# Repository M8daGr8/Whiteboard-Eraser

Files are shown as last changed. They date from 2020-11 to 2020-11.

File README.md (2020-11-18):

# Whiteboard Eraser
Joystick controlled whiteboard eraser.

## Joystick
### PCB
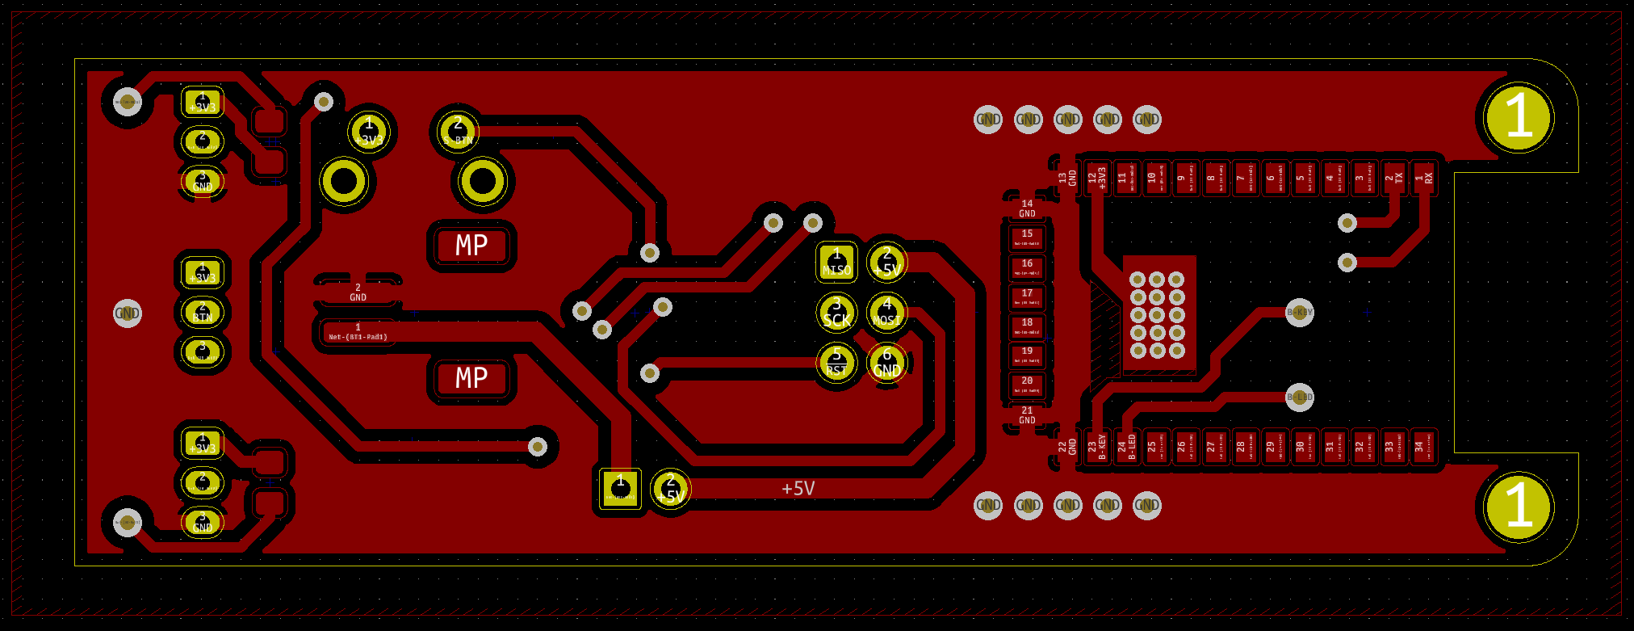
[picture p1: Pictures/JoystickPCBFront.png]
Joy-PCB-Front Joystick PCB Front

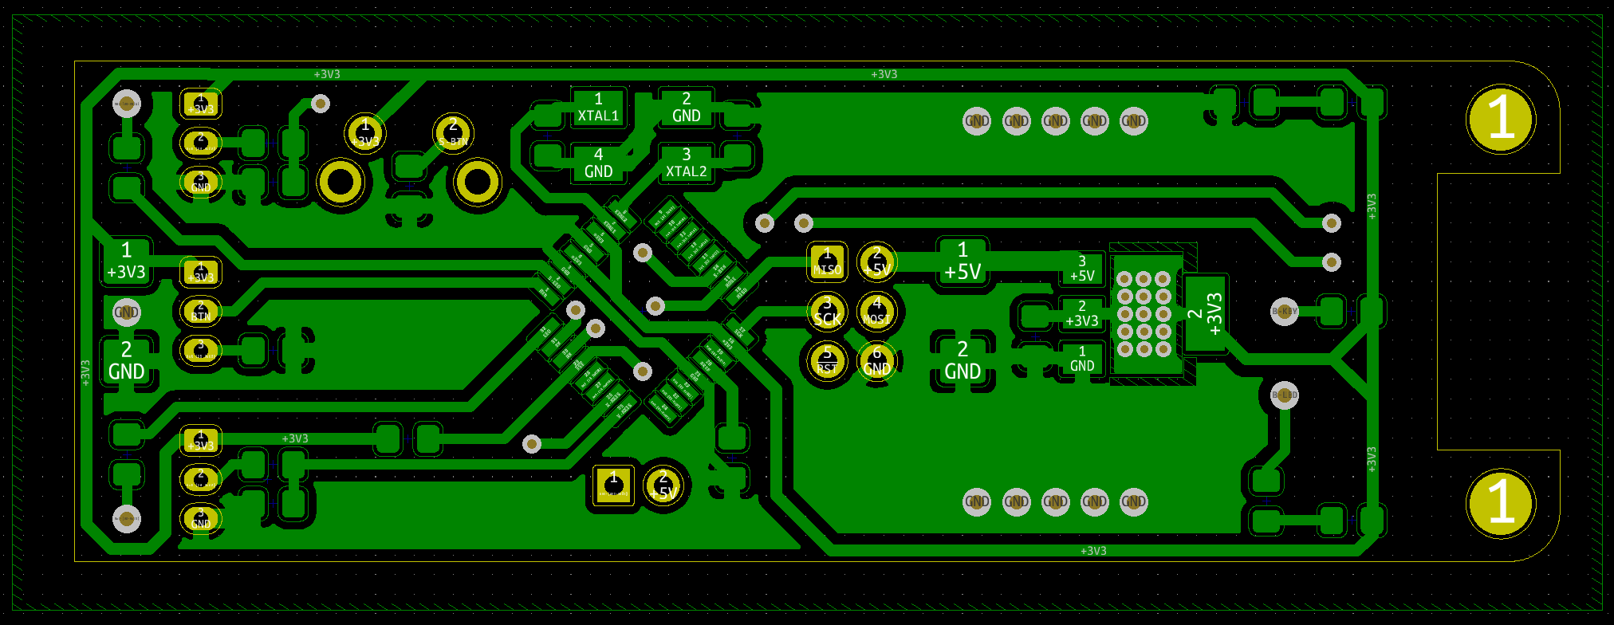
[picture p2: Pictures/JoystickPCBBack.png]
Joy-PCB-Back Joystick PCB Back

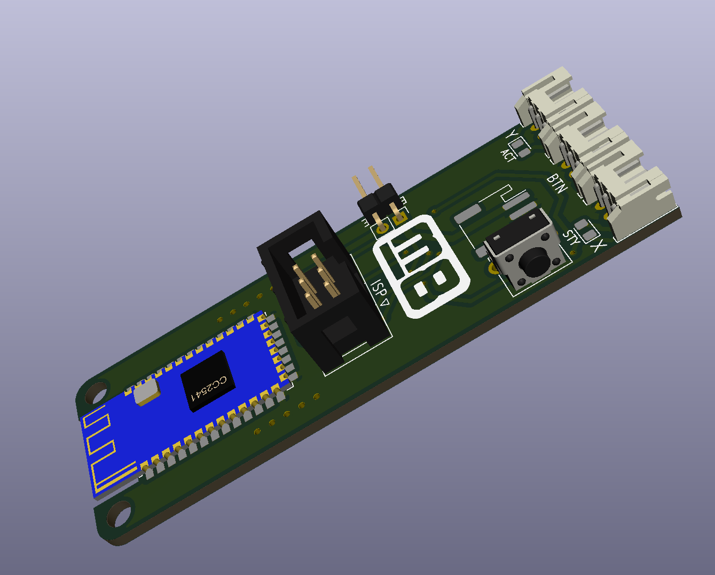
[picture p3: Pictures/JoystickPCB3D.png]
Joy-PCB-3D Joystick PCB 3D


### CAD
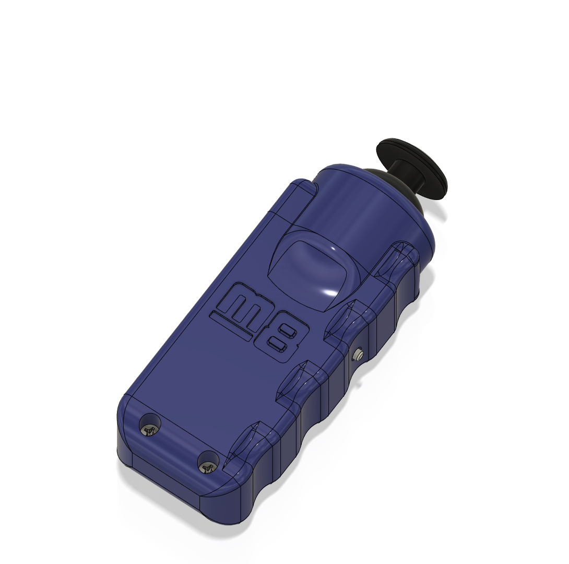
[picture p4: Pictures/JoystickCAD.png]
Joy-CAD Joystick CAD


## Eraser
### PCB
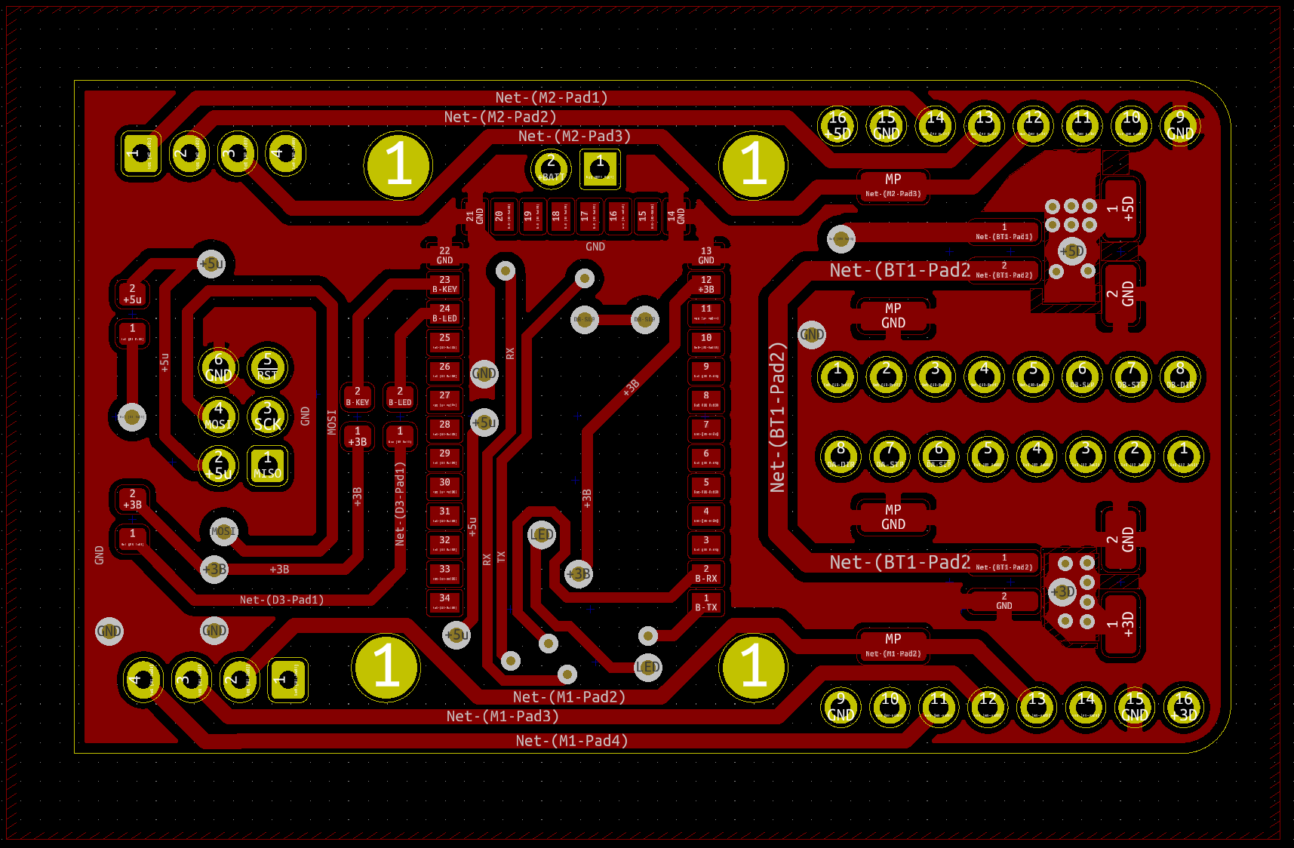
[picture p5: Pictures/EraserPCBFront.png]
Era-PCB-Front Eraser PCB Front

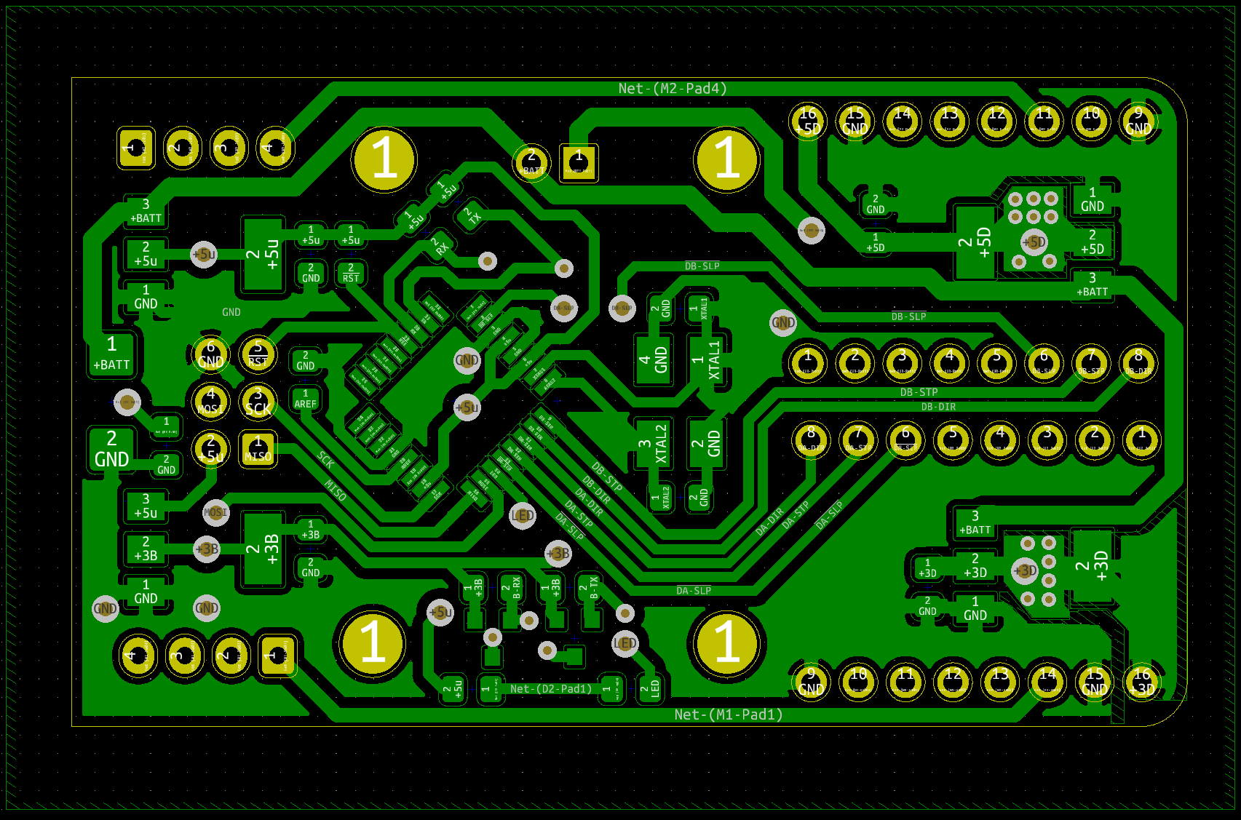
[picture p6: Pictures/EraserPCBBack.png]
Era-PCB-Back Eraser PCB Back

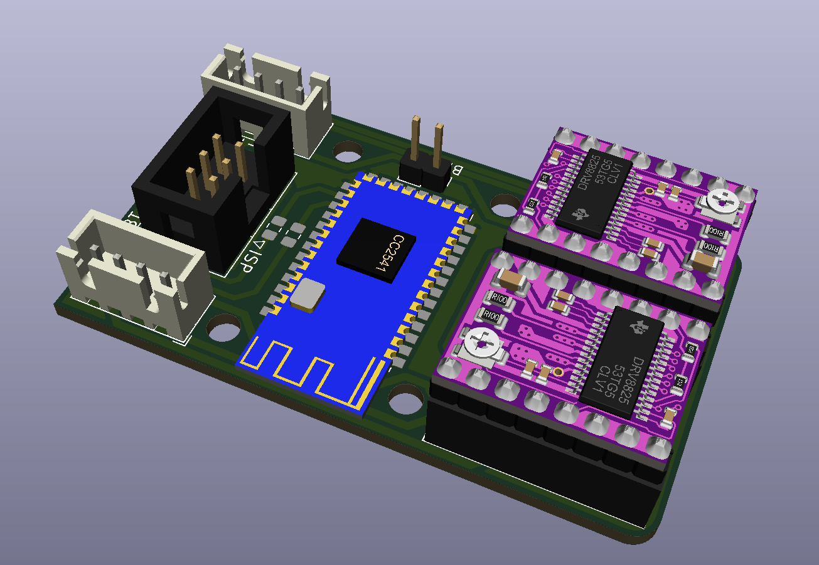
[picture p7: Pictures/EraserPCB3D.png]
Era-PCB-3D Eraser PCB 3D


### CAD
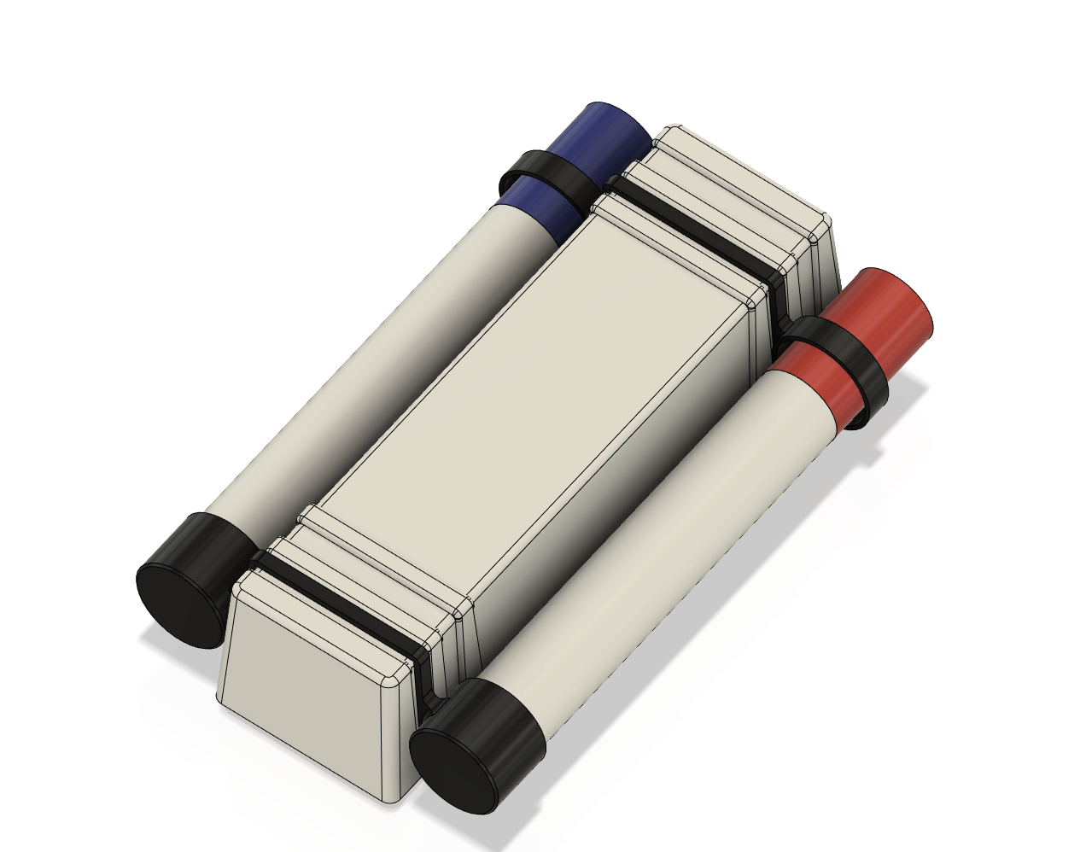
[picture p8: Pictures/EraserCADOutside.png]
Era-CAD-Outside Eraser CAD Outside

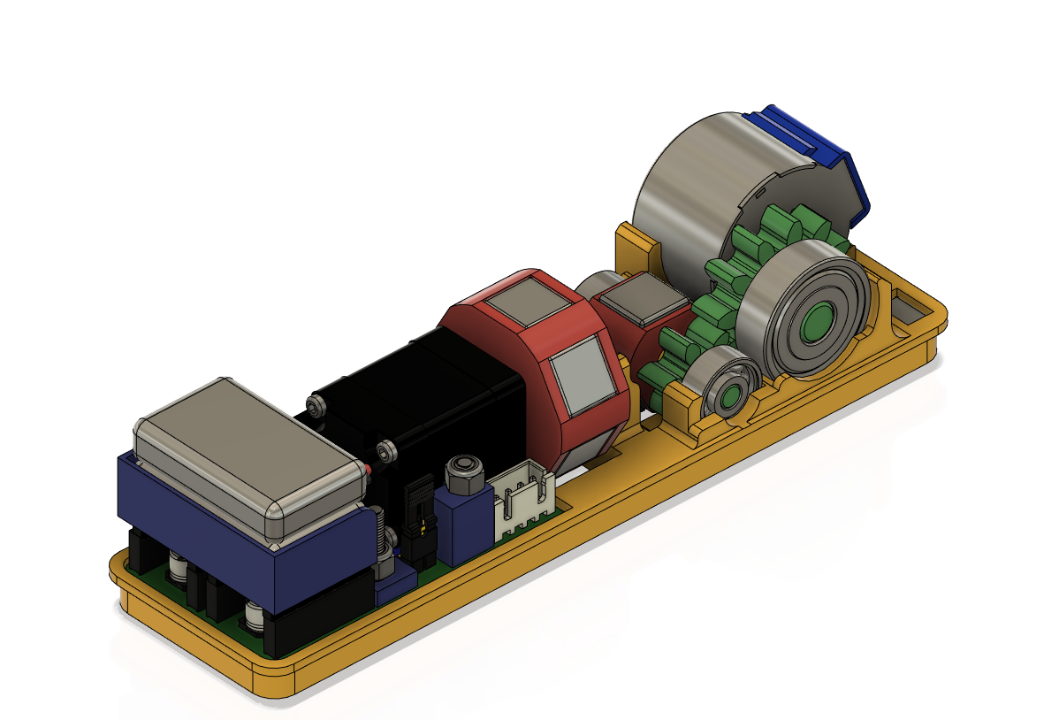
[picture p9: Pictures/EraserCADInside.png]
Era-CAD-Inside Eraser CAD Inside

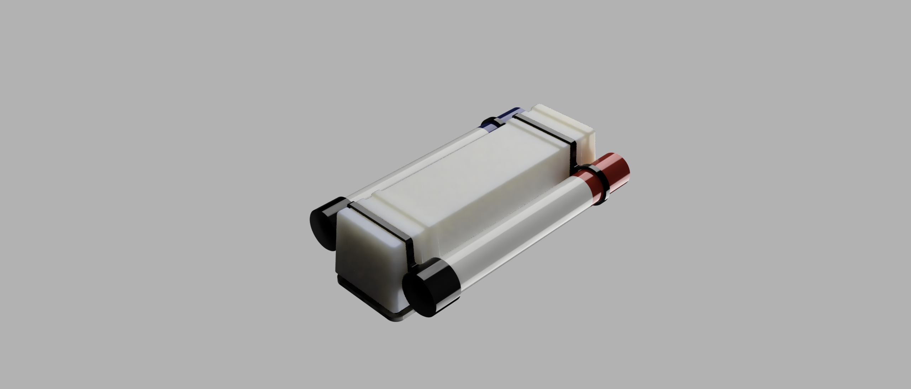
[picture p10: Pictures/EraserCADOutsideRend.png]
Era-CAD-Outside-Rend Eraser CAD Outside Rendered

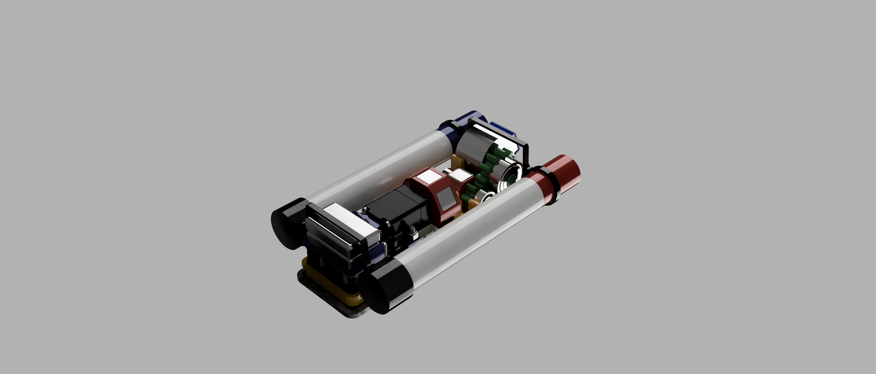
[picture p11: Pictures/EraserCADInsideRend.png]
Era-CAD-Inside-Rend Eraser CAD Inside Rendered


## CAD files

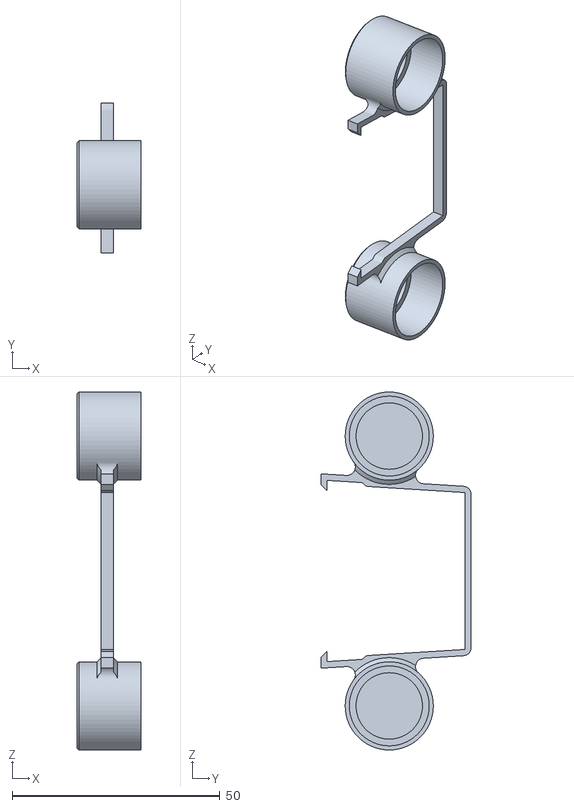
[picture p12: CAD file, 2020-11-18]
Eraser/STL/PenHolderBottom.stl
15.5 x 36.2 x 86.2

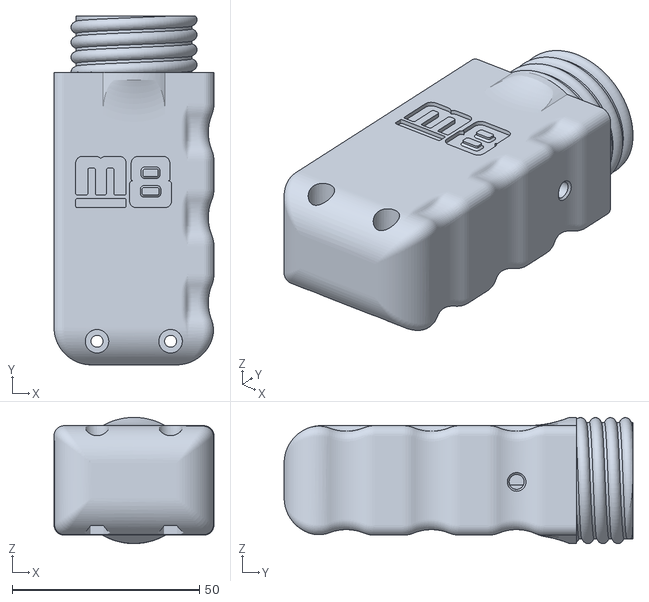
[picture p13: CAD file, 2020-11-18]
Joystick/STL/Handle.stl
42.8 x 93.2 x 33.7

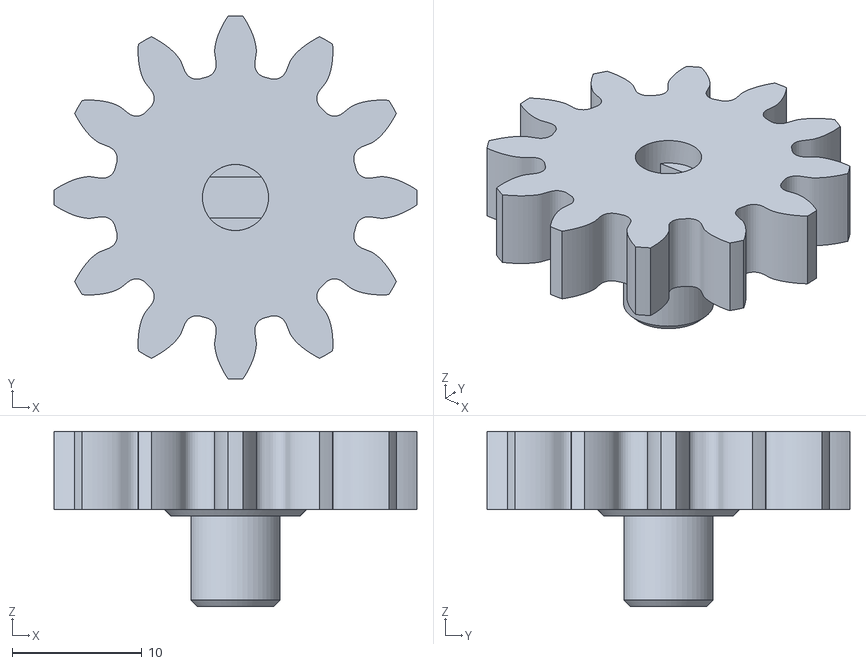
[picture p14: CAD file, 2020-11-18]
Eraser/STL/Y-Axis_Gear(12).stl
28.0 x 28.0 x 13.5

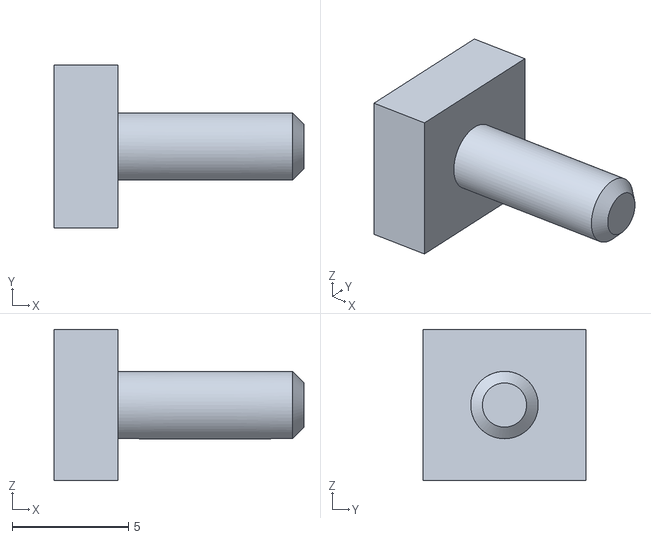
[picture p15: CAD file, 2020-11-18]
Joystick/STL/Button.stl
10.7 x 7.00 x 6.50

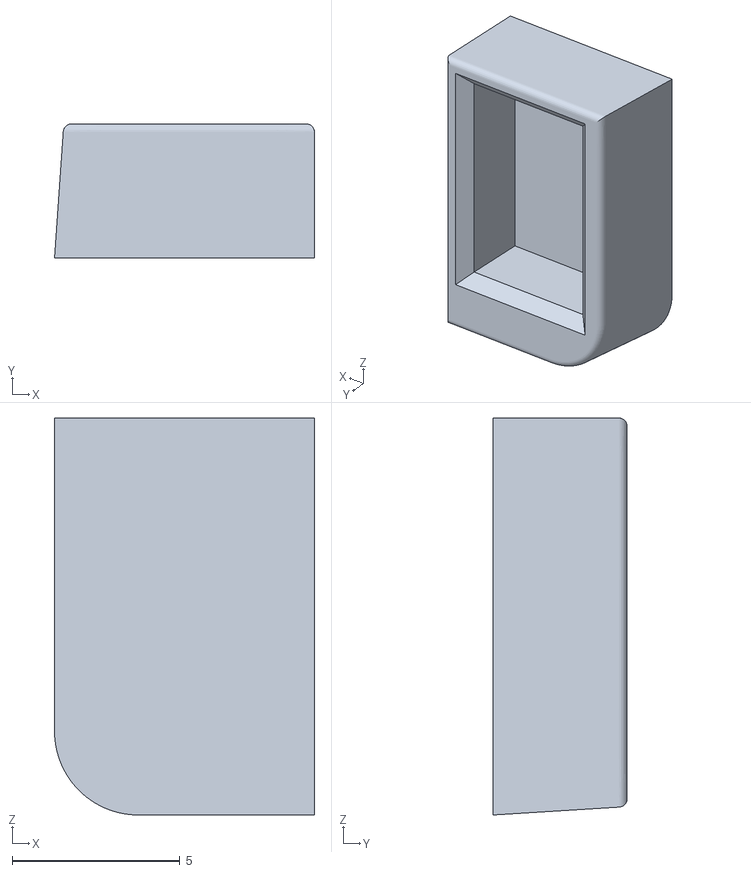
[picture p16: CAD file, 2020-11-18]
Eraser/STL/CoverMagnet.stl
7.74 x 4.00 x 11.8

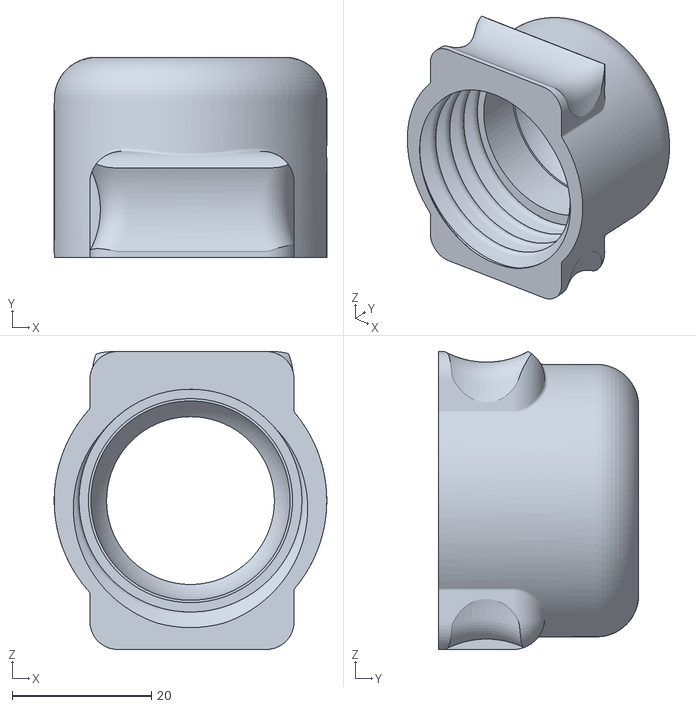
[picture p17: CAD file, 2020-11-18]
Joystick/STL/JoystickCover.stl
39.1 x 28.8 x 42.8

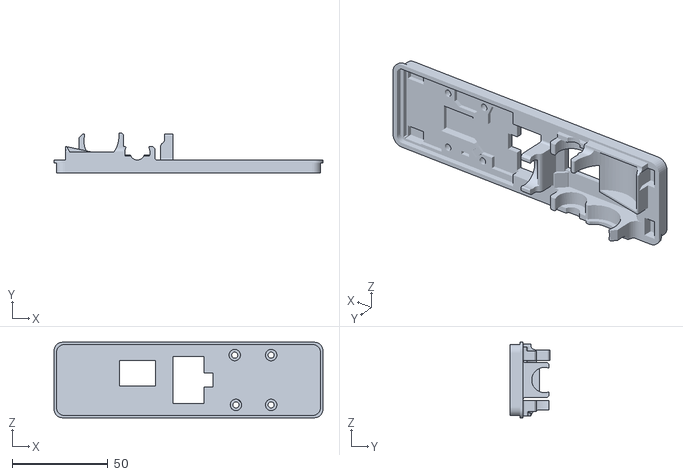
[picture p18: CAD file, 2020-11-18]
Eraser/STL/PCB Base.stl
140.7 x 20.8 x 39.5

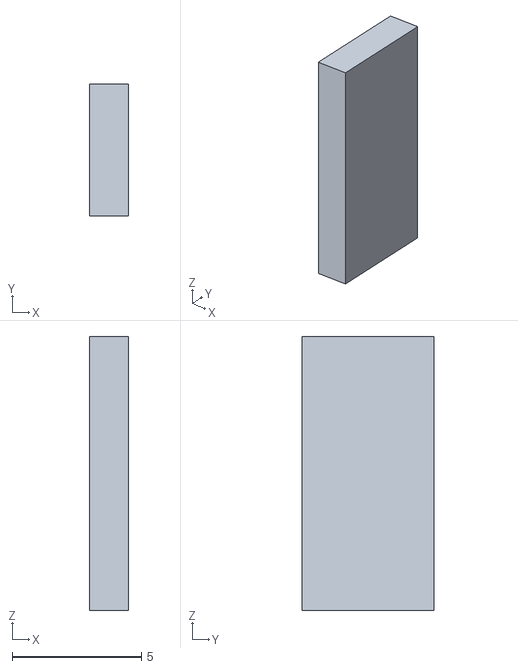
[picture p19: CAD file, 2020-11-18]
Joystick/STL/MagnetCover.stl
1.50 x 5.10 x 10.6

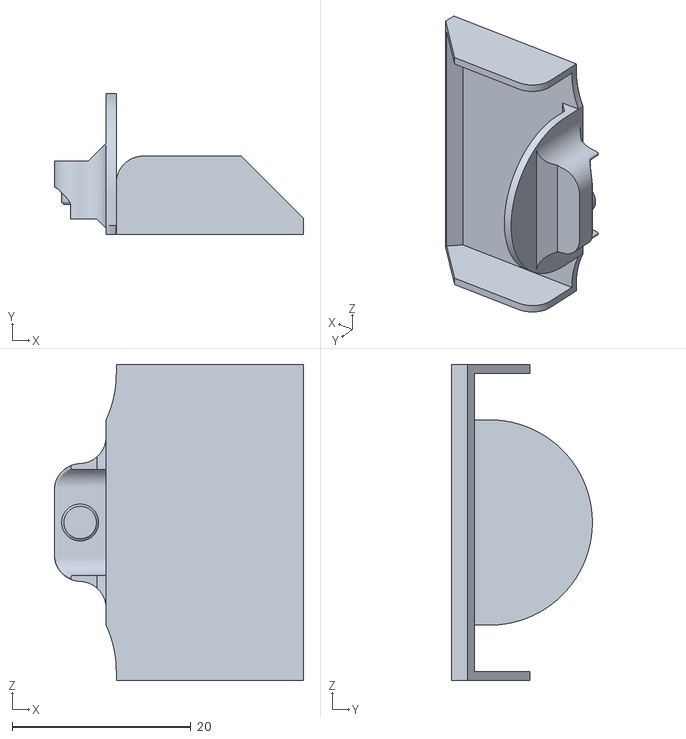
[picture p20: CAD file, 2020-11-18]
Eraser/STL/BatteryHolder.stl
27.9 x 15.8 x 35.4

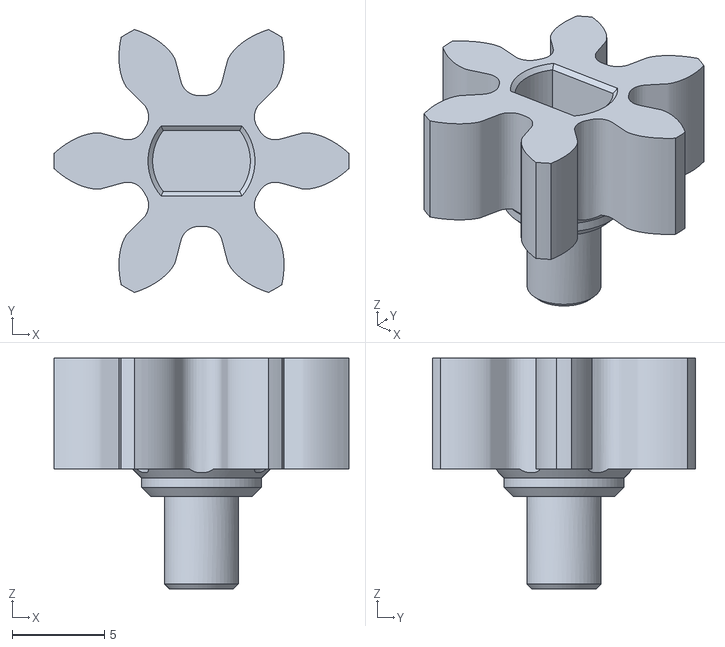
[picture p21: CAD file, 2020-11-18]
Eraser/STL/Y-Axis_Gear(6).stl
16.0 x 14.3 x 12.5

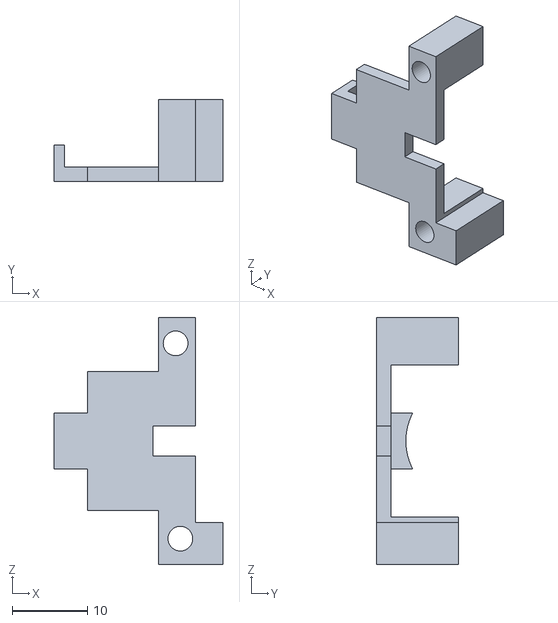
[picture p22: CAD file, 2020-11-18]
Eraser/STL/StepperHolderFront.stl
22.5 x 10.9 x 32.9

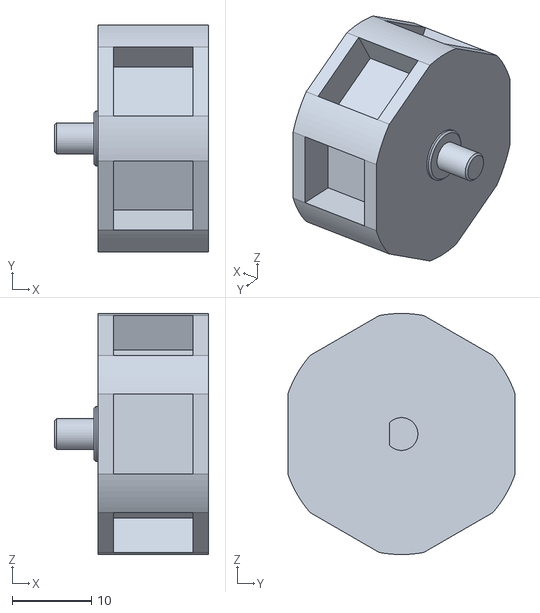
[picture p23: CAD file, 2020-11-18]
Eraser/STL/X-Axis_Wheel(10x10x5mm).stl
19.5 x 28.8 x 30.5

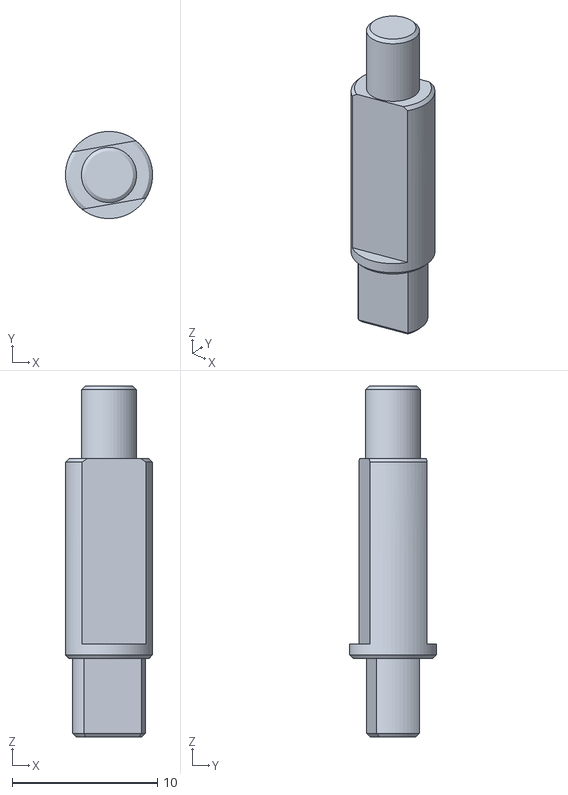
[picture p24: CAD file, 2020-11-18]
Eraser/STL/Y-Axis_Shaft.stl
6.00 x 6.00 x 24.2

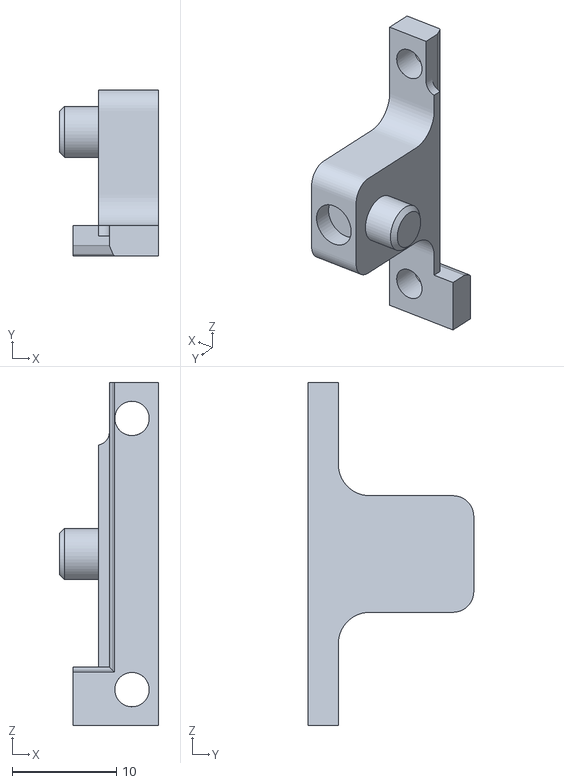
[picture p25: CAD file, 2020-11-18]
Eraser/STL/StepperHolderBack.stl
9.55 x 15.9 x 32.9

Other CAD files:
Eraser/STL/PenHolderTop.stl
Eraser/STL/Y-Axis_Wheel(8x4mm).stl
Eraser/STL/Y-Axis_Wheel(10x10x5mm).stl

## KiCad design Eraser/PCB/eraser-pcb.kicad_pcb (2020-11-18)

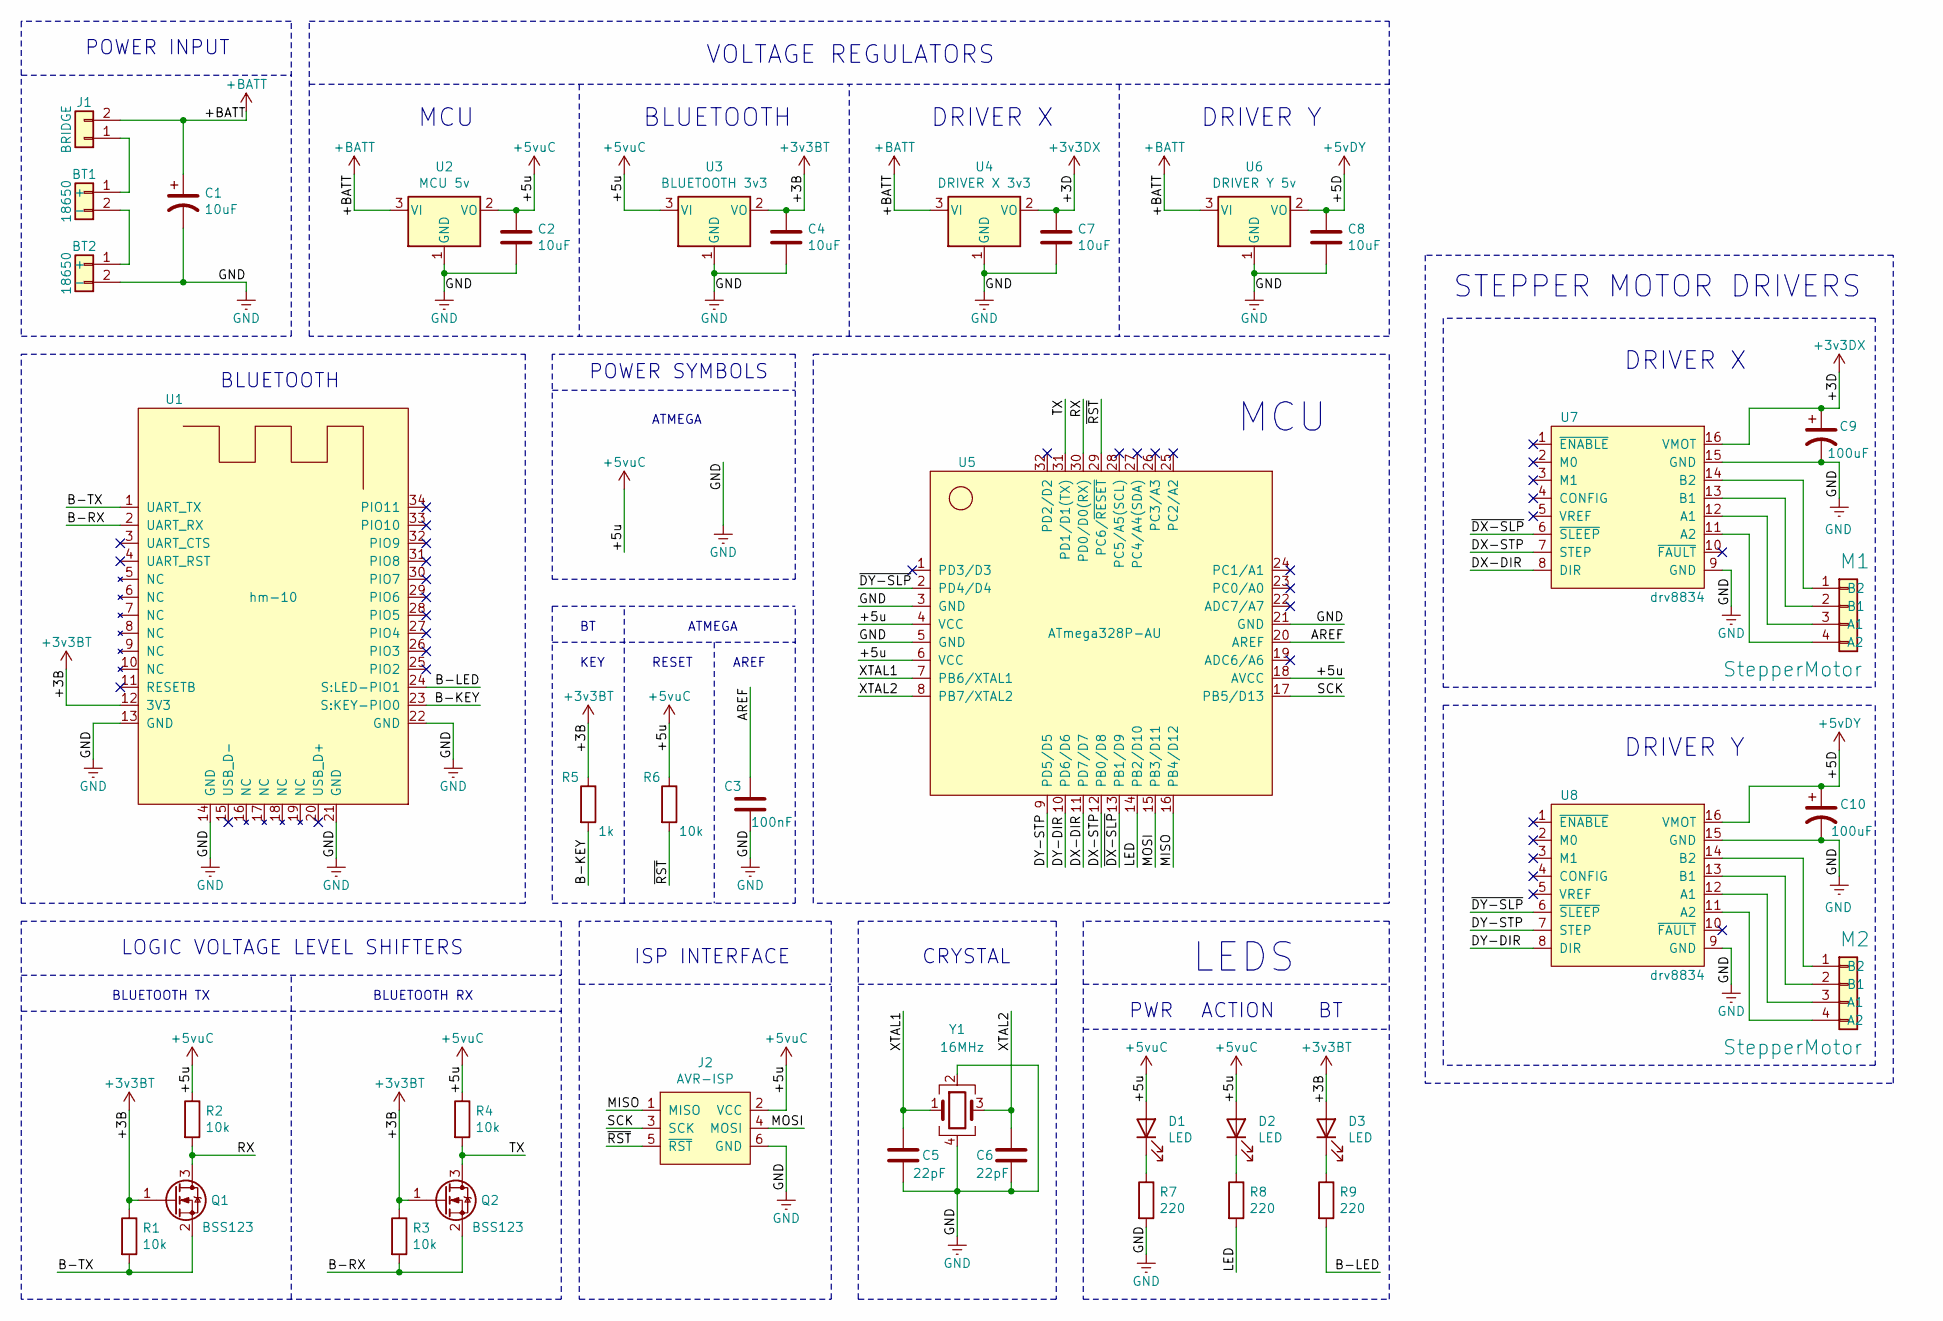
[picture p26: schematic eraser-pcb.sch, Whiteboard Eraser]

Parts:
BT1, BT2: 18650; JST_PH_S2B-PH-SM4-TB_1x02-1MP_P2.00mm_Horizontal
C1: 10uF; CP_EIA-6032-28_Kemet-C_Pad2.25x2.35mm_HandSolder
C2, C4, C7, C8: 10uF; C_0805_2012Metric_Pad1.15x1.40mm_HandSolder
C3: 100nF; C_0805_2012Metric_Pad1.15x1.40mm_HandSolder
C5, C6: 22pF; C_0805_2012Metric_Pad1.15x1.40mm_HandSolder
C9, C10: 100uF; CP_Elec_5x5.3
D1, D2, D3: LED; LED_0805_2012Metric_Pad1.15x1.40mm_HandSolder
J1: BRIDGE; PinHeader_1x02_P2.54mm_Vertical
J2: AVR-ISP; IDC-Header_2x03_P2.54mm_Vertical
M1, M2: StepperMotor; JST_XH_B4B-XH-A_1x04_P2.50mm_Vertical
Q1, Q2: BSS123; SOT-23
R1, R2, R3, R4, R6: 10k; R_0805_2012Metric_Pad1.15x1.40mm_HandSolder
R5: 1k; R_0805_2012Metric_Pad1.15x1.40mm_HandSolder
R7, R8, R9: 220; R_0805_2012Metric_Pad1.15x1.40mm_HandSolder
U1: hm-10
U2: MCU 5v; SOT-223-3_TabPin2
U3: BLUETOOTH 3v3; SOT-223-3_TabPin2
U4: DRIVER X 3v3; SOT-223-3_TabPin2
U5: ATmega328P-AU; TQFP-32_7x7mm_P0.8mm
U6: DRIVER Y 5v; SOT-223-3_TabPin2
U7, U8: drv8834
Y1: 16MHz; CFPX_104-5x3.2mm

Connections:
+BATT: C1.1, J1.2, U2.3 (VI), U4.3 (VI), U6.3 (VI)
/+3B: C4.1, D3.2 (A), Q1.1 (G), Q2.1 (G), R1.1, R3.1, R5.1, U1.12 (3V3), U3.2 (VO)
/+3D: C7.1, C9.1, U4.2 (VO), U7.16 (VMOT)
/+5D: C8.1, C10.1, U6.2 (VO), U8.16 (VMOT)
/+5u: C2.1, D1.2 (A), D2.2 (A), J2.2 (VCC), R2.1, R4.1, R6.1, U2.2 (VO), U3.3 (VI), U5.4 (VCC), U5.6 (VCC), U5.18 (AVCC)
/AREF: C3.1, U5.20 (AREF)
/B-KEY: R5.2, U1.23 (S:KEY-PIO0)
/B-LED: R9.2, U1.24 (S:LED-PIO1)
/B-RX: Q2.2 (S), R3.2, U1.2 (UART_RX)
/B-TX: Q1.2 (S), R1.2, U1.1 (UART_TX)
/DA-DIR: U5.11 (PD7/D7), U7.8 (DIR)
/DA-STP: U5.12 (PB0/D8), U7.7 (STEP)
/DB-DIR: U5.10 (PD6/D6), U8.8 (DIR)
/DB-STP: U5.9 (PD5/D5), U8.7 (STEP)
/GND: BT1.MP, BT2.2 (-), BT2.MP, C1.2, C2.2, C3.2, C4.2, C5.2, C6.2, C7.2, C8.2, C9.2, C10.2, J2.6 (GND), R7.2, U1.13 (GND), U1.14 (GND), U1.21 (GND), U1.22 (GND), U2.1 (GND), U3.1 (GND), U4.1 (GND), U5.3 (GND), U5.5 (GND), U5.21 (GND), U6.1 (GND), U7.9 (GND), U7.15 (GND), U8.9 (GND), U8.15 (GND), Y1.2, Y1.4
/LED: R8.2, U5.14 (PB2/D10)
/MISO: J2.1 (MISO), U5.16 (PB4/D12)
/MOSI: J2.4 (MOSI), U5.15 (PB3/D11)
/RX: Q1.3 (D), R2.2, U5.30 (PD0/D0(RX))
/SCK: J2.3 (SCK), U5.17 (PB5/D13)
/TX: Q2.3 (D), R4.2, U5.31 (PD1/D1(TX))
/XTAL1: C5.1, U5.7 (PB6/XTAL1), Y1.1
/XTAL2: C6.1, U5.8 (PB7/XTAL2), Y1.3
/~DA-SLP: U5.13 (PB1/D9), U7.6 (~SLEEP)
/~DB-SLP: U5.2 (PD4/D4), U8.6 (~SLEEP)
/~RST: J2.5 (~RST), R6.2, U5.29 (PC6/~RESET~)
unnamed: BT1.1 (+), J1.1
unnamed: BT1.2 (-), BT2.1 (+)
unnamed: D1.1 (K), R7.1
unnamed: D2.1 (K), R8.1
unnamed: D3.1 (K), R9.1
unnamed: M1.1 (B2), U7.14 (B2)
unnamed: BT2.MP, M1.2 (B1), U7.13 (B1)
unnamed: M1.3 (A1), U7.12 (A1)
unnamed: M1.4 (A2), U7.11 (A2)
unnamed: M2.1 (B2), U8.14 (B2)
unnamed: M2.2 (B1), U8.13 (B1)
unnamed: BT1.MP, M2.3 (A1), U8.12 (A1)
unnamed: M2.4 (A2), U8.11 (A2)

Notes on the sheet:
PWR
ACTION
BLUETOOTH
LEDS
MCU
DRIVER Y
STEPPER MOTOR DRIVERS
DRIVER X
POWER INPUT
VOLTAGE REGULATORS
ISP INTERFACE
RESET
CRYSTAL
ATMEGA
POWER SYMBOLS
KEY
AREF
LOGIC VOLTAGE LEVEL SHIFTERS
BLUETOOTH RX
BLUETOOTH TX

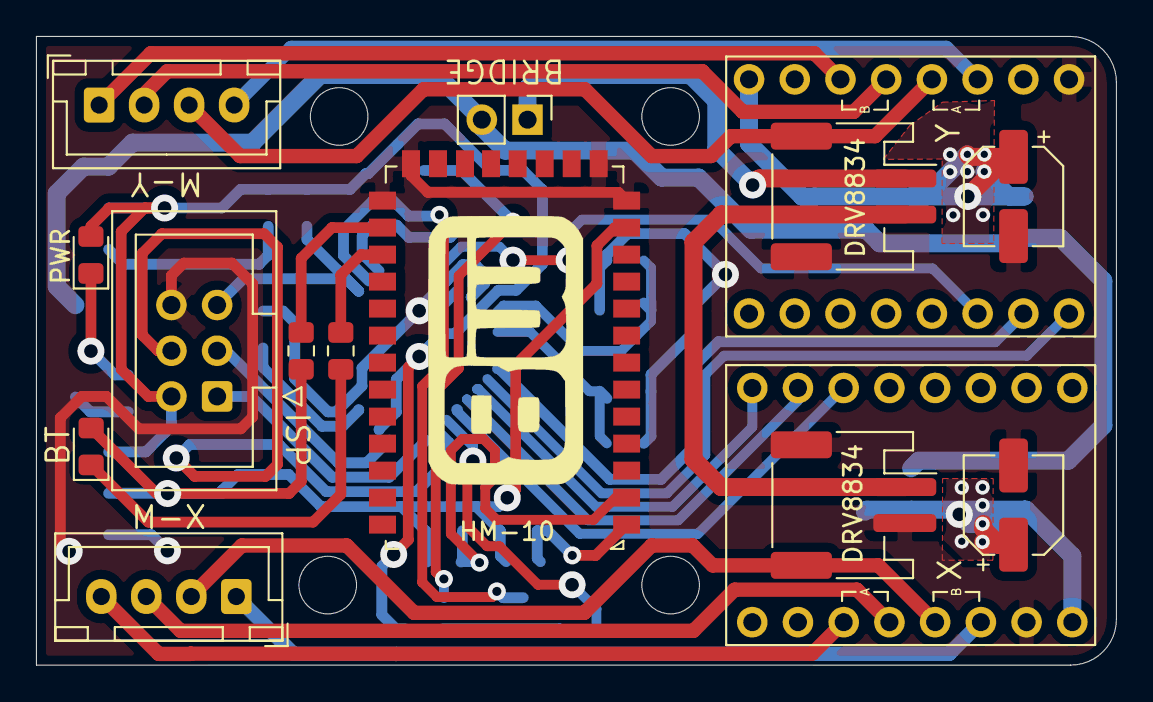
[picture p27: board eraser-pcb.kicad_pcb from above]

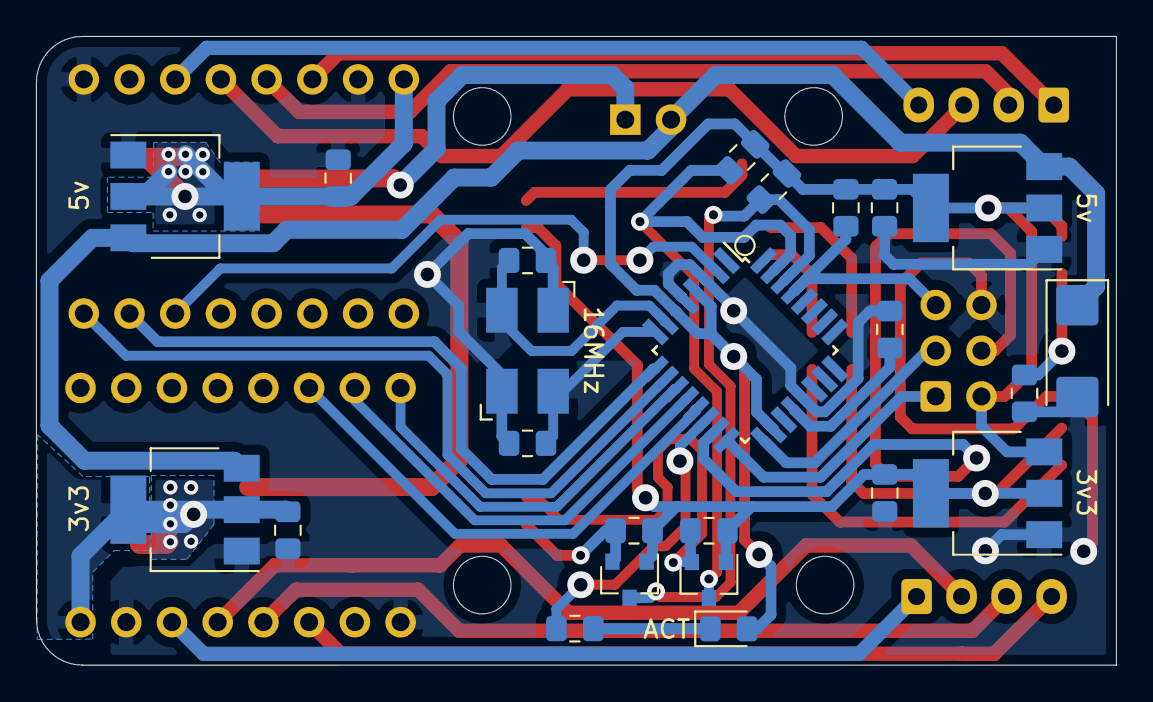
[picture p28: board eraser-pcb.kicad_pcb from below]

Board: 2 copper layers, 60.0 x 34.9 mm, 39 parts (24 on the bottom side), 39 nets.

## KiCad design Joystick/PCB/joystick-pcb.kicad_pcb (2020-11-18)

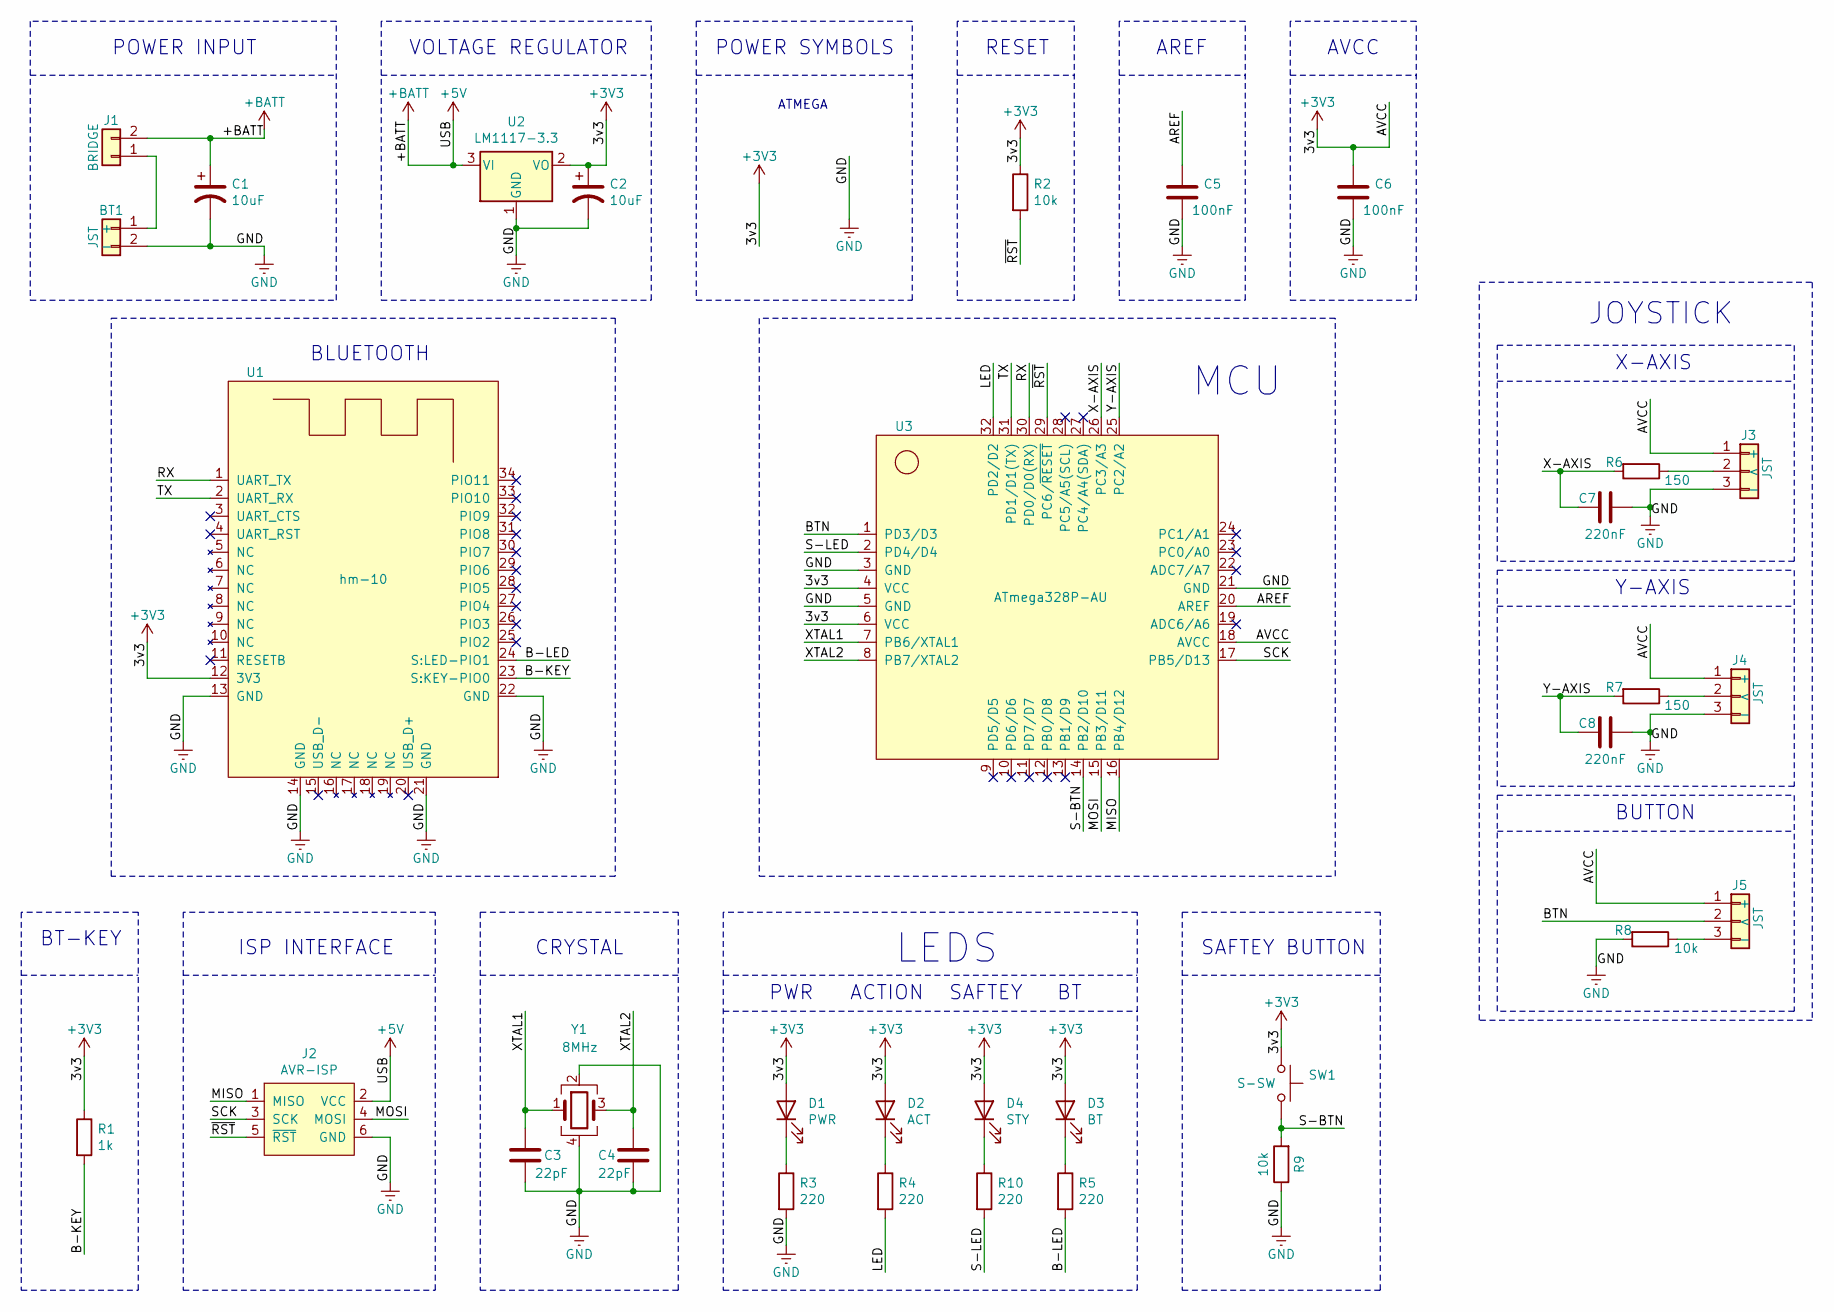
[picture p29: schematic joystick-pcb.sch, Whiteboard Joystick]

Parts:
BT1: JST; JST_PH_S2B-PH-SM4-TB_1x02-1MP_P2.00mm_Horizontal
C1, C2: 10uF; CP_EIA-6032-28_Kemet-C_Pad2.25x2.35mm_HandSolder
C3, C4: 22pF; C_0805_2012Metric_Pad1.15x1.40mm_HandSolder
C5, C6: 100nF; C_0805_2012Metric_Pad1.15x1.40mm_HandSolder
C7, C8: 220nF; C_0805_2012Metric_Pad1.15x1.40mm_HandSolder
D1: PWR; LED_0805_2012Metric_Pad1.15x1.40mm_HandSolder
D2: ACT; LED_0805_2012Metric_Pad1.15x1.40mm_HandSolder
D3: BT; LED_0805_2012Metric_Pad1.15x1.40mm_HandSolder
D4: STY; LED_0805_2012Metric_Pad1.15x1.40mm_HandSolder
J1: BRIDGE; PinHeader_1x02_P2.54mm_Vertical
J2: AVR-ISP; IDC-Header_2x03_P2.54mm_Vertical
J3, J4, J5: JST; JST_PH_S3B-PH-K_1x03_P2.00mm_Horizontal
R1: 1k; R_0805_2012Metric_Pad1.15x1.40mm_HandSolder
R2, R8, R9: 10k; R_0805_2012Metric_Pad1.15x1.40mm_HandSolder
R3, R4, R5, R10: 220; R_0805_2012Metric_Pad1.15x1.40mm_HandSolder
R6, R7: 150; R_0805_2012Metric_Pad1.15x1.40mm_HandSolder
SW1: S-SW; SW_Tactile_SPST_Angled_PTS645Vx39-2LFS
U1: hm-10
U2: LM1117-3.3; SOT-223-3_TabPin2
U3: ATmega328P-AU; TQFP-32_7x7mm_P0.8mm
Y1: 8MHz; CFPX_104-5x3.2mm

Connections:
+3V3: C2.1, C6.1, D1.2 (A), D2.2 (A), D3.2 (A), D4.2 (A), J3.1 (+), J4.1 (+), J5.1 (+), R1.1, R2.1, SW1.1, U1.12 (3V3), U2.2 (VO), U3.4 (VCC), U3.6 (VCC), U3.18 (AVCC)
+5V: C1.1, J1.2, J2.2 (VCC), U2.3 (VI)
/AREF: C5.1, U3.20 (AREF)
/B-KEY: R1.2, U1.23 (S:KEY-PIO0)
/B-LED: R5.2, U1.24 (S:LED-PIO1)
/BTN: J5.2 (<), U3.1 (PD3/D3)
/GND: BT1.2 (-), C1.2, C2.2, C3.2, C4.2, C5.2, C6.2, C7.1, C8.1, J2.6 (GND), J3.3 (-), J4.3 (-), R3.2, R8.2, R9.1, U1.13 (GND), U1.14 (GND), U1.21 (GND), U1.22 (GND), U2.1 (GND), U3.3 (GND), U3.5 (GND), U3.21 (GND), Y1.2, Y1.4
/LED: R4.2, U3.32 (PD2/D2)
/MISO: J2.1 (MISO), U3.16 (PB4/D12)
/MOSI: J2.4 (MOSI), U3.15 (PB3/D11)
/RX: U1.1 (UART_TX), U3.30 (PD0/D0(RX))
/S-BTN: R9.2, SW1.2, U3.14 (PB2/D10)
/S-LED: R10.2, U3.2 (PD4/D4)
/SCK: J2.3 (SCK), U3.17 (PB5/D13)
/TX: U1.2 (UART_RX), U3.31 (PD1/D1(TX))
/X-AXIS: C7.2, R6.2, U3.26 (PC3/A3)
/XTAL1: C3.1, U3.7 (PB6/XTAL1), Y1.1
/XTAL2: C4.1, U3.8 (PB7/XTAL2), Y1.3
/Y-AXIS: C8.2, R7.2, U3.25 (PC2/A2)
/~RST: J2.5 (~RST), R2.2, U3.29 (PC6/~RESET~)
unnamed: BT1.1 (+), J1.1
unnamed: D1.1 (K), R3.1
unnamed: D2.1 (K), R4.1
unnamed: D3.1 (K), R5.1
unnamed: D4.1 (K), R10.1
unnamed: J3.2 (<), R6.1
unnamed: J4.2 (<), R7.1
unnamed: J5.3 (-), R8.1

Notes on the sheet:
CRYSTAL
POWER INPUT
VOLTAGE REGULATOR
ISP INTERFACE
LEDS
POWER SYMBOLS
ATMEGA
PWR
ACTION
BT-KEY
AREF
RESET
JOYSTICK
X-AXIS
MCU
BLUETOOTH
AVCC
SAFTEY BUTTON
SAFTEY
Y-AXIS
BUTTON

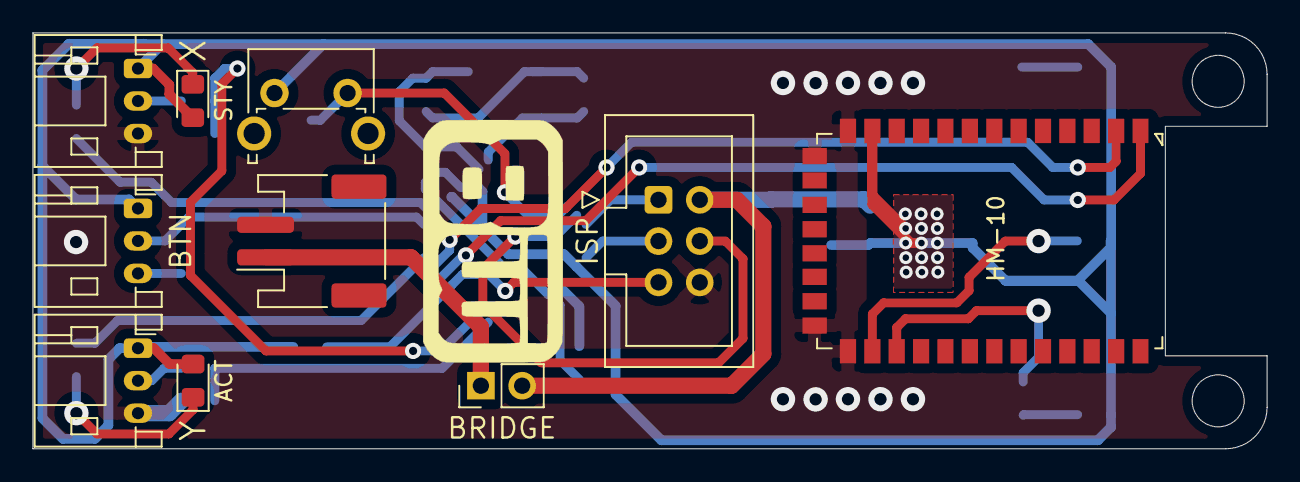
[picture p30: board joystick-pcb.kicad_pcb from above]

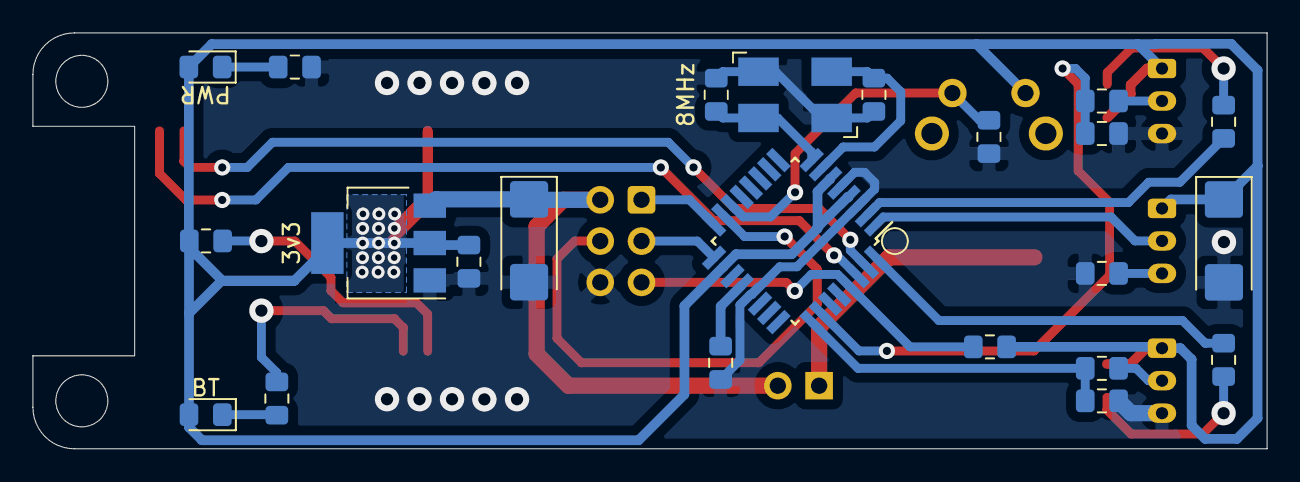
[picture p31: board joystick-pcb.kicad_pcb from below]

Board: 2 copper layers, 75.9 x 25.6 mm, 33 parts (23 on the bottom side), 28 nets.

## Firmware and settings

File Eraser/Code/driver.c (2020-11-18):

#include "driver.h"

#define X_STEP		PORTB0
#define X_DIR		PORTD7
#define X_SLEEP		PORTB1

#define Y_STEP		PORTD5
#define Y_DIR		PORTD6
#define Y_SLEEP		PORTD4

void driver_X_init(void){
	DDRB |= (1 << DDB0) | (1 << DDB1);
	DDRD |= (1 << DDD7);
}

void driver_Y_init(void){
	DDRD |= (1 << DDD5) | (1 << DDD6) | (1 << DDD4);
}

void drivers_init(void){
	driver_X_init();
	driver_Y_init();
}

void driver_X_step_high(void){
	PORTB |= (1 << X_STEP);
}

void driver_X_step_low(void){
	PORTB &= ~(1 << X_STEP);
}

void driver_X_step_toggle(void){
	PORTB ^= (1 << X_STEP);
}

void driver_Y_step_high(void){
	PORTD |= (1 << Y_STEP);
}

void driver_Y_step_low(void){
	PORTD &= ~(1 << Y_STEP);
}

void driver_Y_step_toggle(void){
	PORTD ^= (1 << Y_STEP);
}

void driver_X_sleep_high(void){
	PORTB |= (1 << X_SLEEP);
}

void driver_X_sleep_low(void){
	PORTB &= ~(1 << X_SLEEP);
}

void driver_Y_sleep_high(void){
	PORTD |= (1 << Y_SLEEP);
}

void driver_Y_sleep_low(void){
	PORTD &= ~(1 << Y_SLEEP);
}

/*
	Sätter direction pin beroende på input
*/
void driver_X_set_direction(XDir dir){
	if(dir == FORWARD)
		PORTD &= ~(1 << X_DIR);
	else
		PORTD |= (1 << X_DIR);
}

/*
	Sätter direction pin beroende på input
*/
void driver_Y_set_direction(YDir dir){
	if(dir == UP)
		PORTD |= (1 << Y_DIR);
	else
		PORTD &= ~(1 << Y_DIR);
}

/*
	Stoppar x driver
	ATOMIC_BLOCK för att forca stopp
*/
void driver_X_stop(void){
	ATOMIC_BLOCK(ATOMIC_FORCEON){
		driver_X_sleep_low();
		driver_X_step_low();
	}
}

/*
	Stoppar y driver
	ATOMIC_BLOCK för att forca stopp
*/
void driver_Y_stop(void){
	ATOMIC_BLOCK(ATOMIC_FORCEON){
		driver_Y_sleep_low();
		driver_Y_step_low();
	}
}

/*
	Stoppar alla drivers
	ATOMIC_BLOCK för att forca att de stoppas
*/
void drivers_stop(void){
	ATOMIC_BLOCK(ATOMIC_FORCEON){
		driver_X_stop();
		driver_Y_stop();
	}
}

/*
	UNDER CONSTRUCTION
	detta är en map funktion som inte används just nu.
*/
uint8_t map_value(int16_t value, uint8_t inMin, uint8_t inMax, uint8_t outMin, uint8_t outMax){
	return (abs((((value - inMin) * (outMax - outMin)) / (inMax - inMin))) + outMin);
}

/*
	UNDER CONSTRUCTION
	denna samt map_value är tänkt att fixas för en smooth acceleration och de-acceleration
*/
uint8_t get_speed(int16_t joystickValue, int8_t acceleration){
	return map_value(abs(joystickValue), 6, 130, 40, 1) ;
} 

/*
	denna körs om mode == free varje 0.1 ms
	tar x axis value och kollar "döda vinkeln" / mid point.

	annars steppar motorn och väljer direction varanan gång
*/
void driver_X_go(int16_t xValue){
	
	if(xValue < 5 && xValue > -5){
		driver_X_stop();
	}
	else {
		static uint8_t count = 0;
		
		if(count++ >= 1){
			driver_X_sleep_high();
			driver_X_set_direction((xValue > 0) ? FORWARD : BACKWARD);
			driver_X_step_toggle();
			count = 0;
		}
	}
}

/*
	denna körs om mode == free varje 0.1 ms
	tar x axis value och kollar "döda vinkeln" / mid point.

	annars steppar motorn och väljer direction varanan gång
*/
void driver_Y_go(int16_t yValue){
	if(yValue < 5 && yValue > -5){
		driver_Y_stop();
	}
	else {
		static uint8_t count = 0;
		
		if(count++ >= 1){
			driver_Y_sleep_high();
			driver_Y_set_direction((yValue > 0) ? UP : DOWN);
			driver_Y_step_toggle();
			count = 0;
		}
	}
}

void drivers_go(Joystick joystick){
	driver_X_go(joystick.xAxis);
	driver_Y_go(joystick.yAxis);
}

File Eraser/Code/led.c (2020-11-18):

#include "led.h"

#define LED PORTB2

void led_init(void){
	DDRB |= (1 << DDB2);
	PORTB |= (1 << LED);
}

void led_low(void){
	PORTB &= ~(1 << LED);
}

void led_high(void){
	PORTB |= (1 << LED);
}

void led_toggle(void){
	PORTB ^= (1 << LED);
}

/*
	Väljer hur leden kommer bete sig beroende på vilket läge
	systemet är i.

	Denna körs var 100 ms.
	Dvs.
		"STOP": blink 1 sek
		"FREE": blink 100 ms
*/
void led_show_mode(Mode mode){
	static uint8_t count = 0;
	
	switch(mode){
		case STOP:
			if(count == 10)
				led_toggle();
				break;
		case FREE:
			led_toggle();
			break;
		case CLEAN:
			led_low();
			break;
		default:
			led_high();
			break;
	}
	if(count++ == 10)
		count= 0;
}

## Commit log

2020-11-18 Init commit
    [BatteryHolder.stl, Button.stl, CoverMagnet.stl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]
2020-11-18 changes in code. Added comment and changed eraser timer interrupt
